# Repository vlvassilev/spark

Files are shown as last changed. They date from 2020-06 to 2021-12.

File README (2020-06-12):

Spark is a universal open hardware platform for networking
developed by Lightside Instruments AS.

The project includes schematic and PCB
design files for KiCAD and technical documentation for
production of a 19 inch rack mountable ESD Acrylic box.

The project is published by Lightside Instruments AS
under TAPR Open Hardware License. Read the LICENSE file
for details.

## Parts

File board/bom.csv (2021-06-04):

Reference | Quantity | Identifier | footprint | Value | Tolerance | Voltage | Current | Power | Mfr | Mfr Part # | Notes
P1 | 1 |  | 96boards:Pin_Header_SMD_2x20_Pitch2mm | CONN_02X20 |  |  |  |  | Molex | 87759-4051
P3 | 1 |  | 96boards:61083-063400LF | CONN_02X30 |  |  |  |  | Amphenol | 61083-064400LF
J11;J21;J31;J41;J51;J61 | 6 |  | spark:molex-sfp-plus-747540-101 | SFP+ |  |  |  |  |  | 74754-0101
J1;J2;J3;J4;J5;J6 | 6 |  | spark:molex-sfp-plus-747540-101 | SFP+ |  |  |  |  |  | 74441-0001
J12;J22;J32;J42;J52;J62 | 6 |  | spark:molex-sfp-plus-747540-101 | SFP+ |  |  |  |  |  | 74754-0011
J7 | 1 |  | spark:R-PDSS-B11 | PTH08T221W |  |  |  |  |  | PTH08T221WAZ
R102;R103;R105;R106;R107;R202;R203;R205;R206;R207;R302;R303;R305;R306;R307;R402;R403;R405;R406;R407;R502;R503;R505;R506;R507;R602;R603;R605;R606;R607 | 30 |  | Resistor_SMD:R_0402_1005Metric | 10K |  |  |  |  |  | CRCW040210K0FKEDC
C102;C104;C101;C103;C202;C204;C201;C203;C302;C304;C301;C303;C402;C404;C401;C403;C502;C504;C501;C503;C602;C604;C601;C603 | 24 |  | Capacitor_SMD:C_0402_1005Metric | 100nF |  |  |  |  |  | 885012205037
J10 | 1 |  | spark:PJ1-021-SMT-TR | Barrel_Jack |  |  |  |  |  | PJ1-021-SMT-TR
L102;L101;L202;L201;L302;L301;L402;L401;L502;L501;L602;L601 | 12 |  | Inductor_SMD:L_1210_3225Metric | 4.7uH |  |  |  |  |  | CM322522-4R7JL
C106;C105;C8;C206;C205;C306;C305;C406;C405;C506;C505;C606;C605 | 13 |  | Capacitor_SMD:C_1210_3225Metric | 22uF |  | >=16V |  |  |  | F931C226MBAAJ6 | TAJB226M016SNJ
D101;D201;D301;D401;D501;D601 | 6 |  | LED_SMD:LED_0402_1005Metric | ADM_LED |  |  |  |  |  | 150040VS73240
R101;R104;R201;R204;R301;R304;R401;R404;R501;R504;R601;R604 | 12 |  | Resistor_SMD:R_0402_1005Metric | 1K |  |  |  |  |  | RR0510P-102-D
D102;D202;D302;D402;D502;D602 | 6 |  | LED_SMD:LED_0402_1005Metric | ALARM_LED |  |  |  |  |  | 150040VS73240
R8 | 1 |  | Resistor_SMD:R_0402_1005Metric | 1K21 |  |  |  |  |  | ERJ-2RKF1211X
C7 | 1 |  | Capacitor_Tantalum_SMD:CP_EIA-7343-31_Kemet-D | 330uF |  |  |  |  |  | T491D227M016AT
C9 | 1 |  | Capacitor_Tantalum_SMD:CP_EIA-7343-31_Kemet-D | 220uF |  |  |  |  |  | T491D227M016AT
P2 | 1 |  | 96boards:Socket_Strip_SMD_2x20_Pitch2mm | Conn_02x20_Odd_Even |  |  |  |  | Amphenol | 55510-140LF
J8_1,J8_2 | 2 |  | Connector_PinHeader_2.00mm:PinHeader_2x30_P2.00mm_Vertical_SMD | Conn_02x30_Odd_Even |  |  |  |  | Samtec | TMM-115-01-L-D-SM | Or 1x TMM-130-01-L-D-SM
P5;P4 | 2 |  | Connector_PinHeader_2.54mm:PinHeader_2x20_P2.54mm_Vertical_SMD | Conn_02x20_Odd_Even |  |  |  |  | Harwin | M20-7812045 | Remove the mounting pegs with pleiers before placing the component
SW2 | 1 |  | Button_Switch_SMD:SW_DIP_SPSTx06_Slide_Omron_A6H-6101_W6.15mm_P1.27mm | SW_DIP_x06 |  |  |  |  |  | A6H-6101
P6 | 1 |  | spark:5177983-2 | CONN_02X30 |  |  |  |  | TE CONNECTIVITY | 1-5177983-2
SW1 | 1 |  | Button_Switch_THT:SW_Tactile_SPST_Angled_PTS645Vx83-2LFS | SW_Push |  |  |  |  |  | PTS645VK582LFS
R1 | 1 | * |  | 13.3K |  |  |  |  |  | ERA-2AEB1332X
U1 | 1 | * |  |  |  |  |  |  |  | LTM4624IY#PBF
U2 | 1 |  | Package_SO:SO-8_3.9x4.9mm_P1.27mm | PCA9306 |  |  |  |  |  | PCA9306D
R3,R4,R6,R7 | 4 |  | Resistor_SMD:R_0402_1005Metric | 4K7
R5 | 1 |  | Resistor_SMD:R_0402_1005Metric | 200K

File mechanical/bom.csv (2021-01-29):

Reference | Quantity | Mfr | Mfr Part # | Description
M1 | 4 | Wurth | 971080154 | Standoff 8mm_w_6mm_ext_thread
M2 | 22 | Wurth | 970060154 | Standoff Female-Female 6mm
M3 | 4 | Wurth | 971060154 | Standoff 6mm_w_6mm_ext_thread
M4 | 8 | Essentra | 302208059935 | Standoff Female-Female 8mm

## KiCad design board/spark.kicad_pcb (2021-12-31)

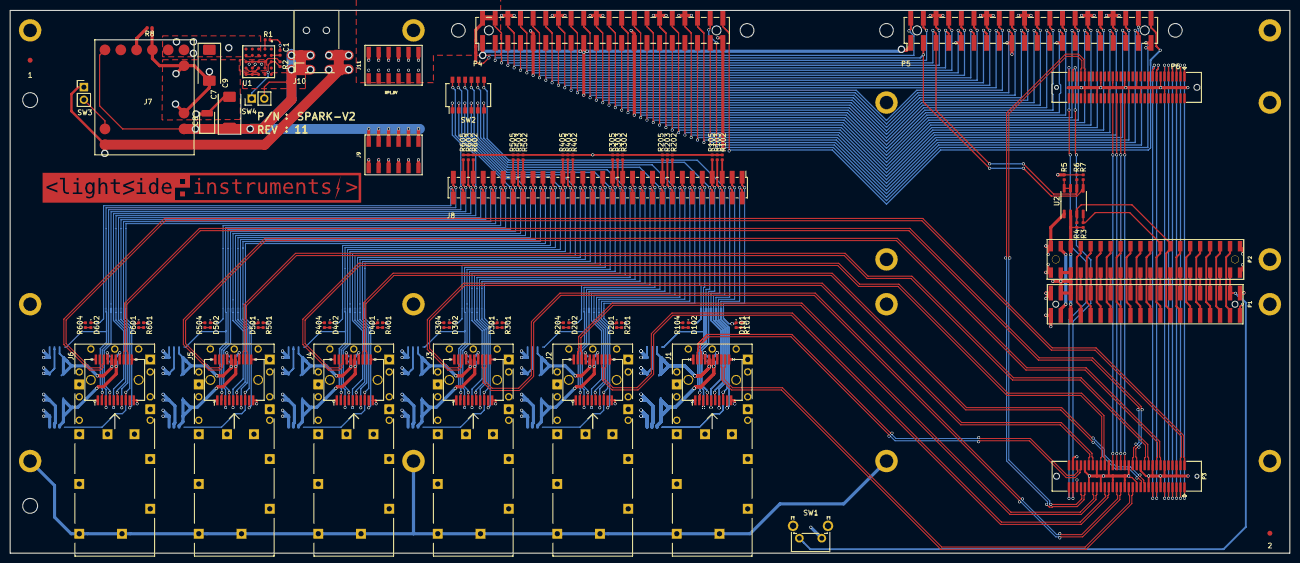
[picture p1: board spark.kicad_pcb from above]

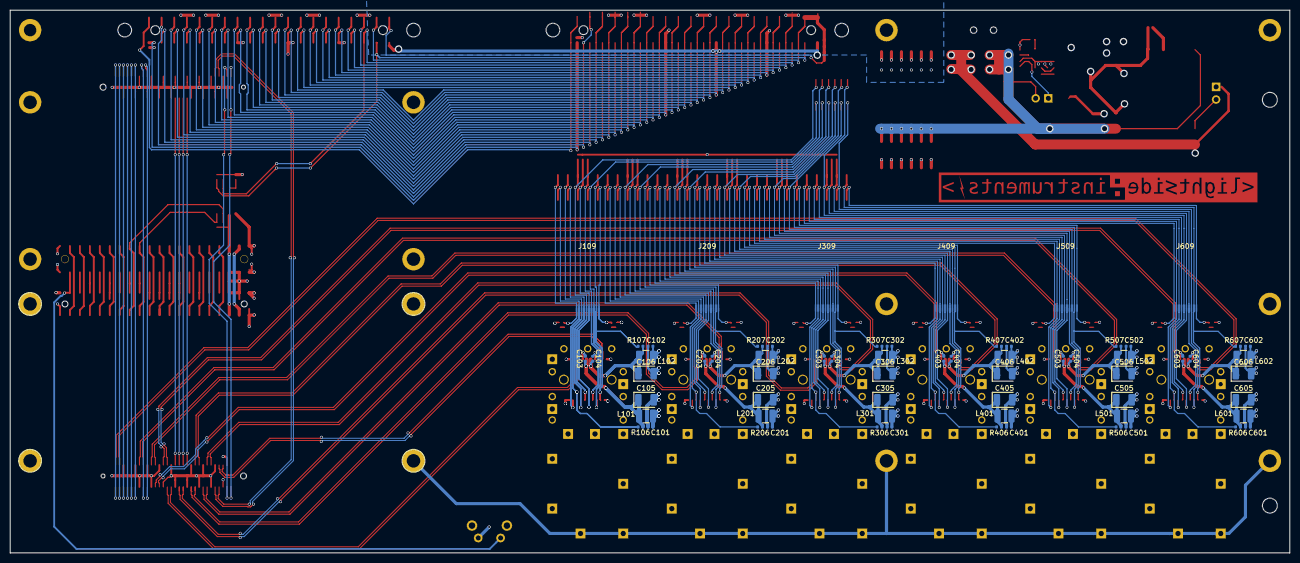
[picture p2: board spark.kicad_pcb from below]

Board: 4 copper layers, 257.0 x 109.0 mm, 145 parts (66 on the bottom side), 198 nets.

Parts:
1, 2: Fiducial_1mm_Mask3mm
C1: C; C_0402_1005Metric
C7: 330uF; CP_EIA-7343-31_Kemet-D
C8, C105, C106, C205, C206, C305, C306, C405, C406, C505, C506, C605, C606: 22uF; CP_EIA-3528-21_Kemet-B
C9: 220uF; CP_EIA-7343-31_Kemet-D
C101, C102, C103, C104, C201, C202, C203, C204, C301, C302, C303, C304, C401, C402, C403, C404, C501, C502, C503, C504, C601, C602, C603, C604: 100nF; C_0402_1005Metric
D101, D201, D301, D401, D501, D601: ADM_LED; LED_0402_1005Metric
D102, D202, D302, D402, D502, D602: ALARM_LED; LED_0402_1005Metric
J1, J2, J3, J4, J5, J6: SFP+; molex-sfp-plus-747540-101
J7: PTH08T221W; R-PDSS-B11
J8: Conn_02x30_Odd_Even; PinHeader_2x30_P2.00mm_Vertical_SMD
J9, J11: Conn_02x06_Odd_Even; Socket_Strip_SMD_2x6_Pitch2mm
J10: Barrel_Jack; PJ1-021-SMT-TR
J109, J209, J309, J409, J509, J609: Conn_01x10; sfp_header
L101, L102, L201, L202, L301, L302, L401, L402, L501, L502, L601, L602: 4.7uH; L_1210_3225Metric
P1: CONN_02X20; Pin_Header_SMD_2x20_Pitch2mm
P2: Conn_02x20_Odd_Even; Socket_Strip_SMD_2x20_Pitch2mm_Alignment_Pin
P3: CONN_02X30; 61083-063400LF
P4, P5: Conn_02x20_Odd_Even; PinSocket_2x20_P2.54mm_Vertical_Inverted_SMD_Alignment_Pin
P6: CONN_02X30; 5177983-2
R1: 13K3; C_0402_1005Metric
R2: 10K; C_0402_1005Metric
R3, R4, R6, R7: 4K7; R_0402_1005Metric
R5: 200K; R_0402_1005Metric
R8: 1K21; R_0402_1005Metric
R101, R104, R201, R204, R301, R304, R401, R404, R501, R504, R601, R604: 1K; R_0402_1005Metric
R102, R103, R105, R106, R107, R202, R203, R205, R206, R207, R302, R303, R305, R306, R307, R402, R403, R405, R406, R407, R502, R503, R505, R506, R507, R602, R603, R605, R606, R607: 10K; R_0402_1005Metric
SW1: SW_Push; SW_Tactile_SPST_Angled_PTS645Vx83-2LFS
SW2: SW_DIP_x06; SW_DIP_SPSTx06_Slide_Omron_A6H-6101_W6.15mm_P1.27mm
SW3, SW4: SW_DIP_x01; PinHeader_1x02_P2.54mm_Vertical
U1: LTM4624IYPBF; Analog_Devices_Inc-BGA-0-05-08-1905_Rev_C-0
U2: PCA9306; SO-8_3.9x4.9mm_P1.27mm

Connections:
+1V8: P1.35, P2.35, R3.1, R4.1, U2.2
+3V3: C9.1, C101.1, C102.1, C201.1, C202.1, C301.1, C302.1, C401.1, C402.1, C501.1, C502.1, C601.1, C602.1, J7.5, J7.6, L101.1, L102.1, L201.1, L202.1, L301.1, L302.1, L401.1, L402.1, L501.1, L502.1, L601.1, L602.1, P4.1, P4.17, P5.1, P5.17, R5.1, R6.1, R7.1, R101.1, R102.1, R103.1, R104.1, R105.1, R201.1, R202.1, R203.1, R204.1, R205.1, R301.1, R302.1, R303.1, R304.1, R305.1, R401.1, R402.1, R403.1, R404.1, R405.1, R501.1, R502.1, R503.1, R504.1, R505.1, R601.1, R602.1, R603.1, R604.1, R605.1, U1.C1, U1.D1, U1.D2, U1.E1, U1.E2
+5V: P1.37, P2.37
CHASSIS: J1.CAGE, J2.CAGE, J3.CAGE, J4.CAGE, J5.CAGE, J6.CAGE
CLK0/CSI0_MCLK: P3.15, P6.15
CLK1/CSI1_MCLK: P3.17, P6.17
CSI0_C+: J6.18, P3.2
CSI0_C-: J6.19, P3.4
CSI0_D1+: J5.18, P3.14
CSI0_D1-: J5.19, P3.16
CSI0_D2+: J5.13, P3.20
CSI0_D2-: J5.12, P3.22
CSI0_D3+: J6.13, P3.26
CSI0_D3-: J6.12, P3.28
CSI1_C+: J1.18, P3.54
CSI1_C-: J1.19, P3.56
CSI1_D0+: J4.18, P3.42
CSI1_D0-: J4.19, P3.44
CSI1_D1+: J3.18, P3.48
CSI1_D1-: J3.19, P3.50
DSI_CLK+: J4.13, P3.21
DSI_CLK-: J4.12, P3.23
DSI_D0+: J1.13, P3.27
DSI_D0-: J1.12, P3.29
DSI_D1+: J3.13, P3.33
DSI_D1-: J3.12, P3.35
DSI_D2+: J2.13, P3.39
DSI_D2-: J2.12, P3.41
DSI_D3+: J2.18, P3.45
DSI_D3-: J2.19, P3.47
GND: C1.2, C7.2, C8.2, C9.2, C101.2, C102.2, C103.2, C104.2, C105.2, C106.2, C201.2, C202.2, C203.2, C204.2, C205.2, C206.2, C301.2, C302.2, C303.2, C304.2, C305.2, C306.2, C401.2, C402.2, C403.2, C404.2, C405.2, C406.2, C501.2, C502.2, C503.2, C504.2, C505.2, C506.2, C601.2, C602.2, C603.2, C604.2, C605.2, C606.2, J1.1, J1.10, J1.11, J1.14, J1.17, J1.20, J2.1, J2.10, J2.11, J2.14, J2.17, J2.20, J3.1, J3.10, J3.11, J3.14, J3.17, J3.20, J4.1, J4.10, J4.11, J4.14, J4.17, J4.20, J5.1, J5.10, J5.11, J5.14, J5.17, J5.20, J6.1, J6.10, J6.11, J6.14, J6.17, J6.20, J7.1, J7.3, J7.4, J7.7, J9.1, J9.3, J9.5, J9.7, J9.9, J9.11, J10.2, J10.3, J11.2, J11.4, J11.6, J11.8, J11.10, J11.12, P1.1, P1.2, P1.39, P1.40, P2.1, P2.2, P2.39, P2.40, P3.6, P3.12, P3.13, P3.18, P3.19, P3.24, P3.25, P3.30, P3.31, P3.37, P3.40, P3.43, P3.46, P3.49, P3.52, P3.55, P3.58, P4.6, P4.9, P4.14, P4.20, P4.25, P4.30, P4.34, P4.39, P5.6, P5.9, P5.14, P5.20, P5.25, P5.30, P5.34, P5.39, P6.6, P6.12, P6.13, P6.18, P6.19, P6.24, P6.25, P6.30, P6.31, P6.37, P6.40, P6.43, P6.46, P6.49, P6.52, P6.55, P6.58, R1.2, R2.2, R8.1, SW1.1, SW3.1, U1.B3, U1.B4, U1.C3, U1.D3, U1.D4, U1.E3, U2.1
GPIO_A: P1.23, P2.23
GPIO_B: P1.24, P2.24
GPIO_C: P1.25, P2.25
GPIO_D: P1.26, P2.26
GPIO_E: P1.27, P2.27
GPIO_F: P1.28, P2.28
GPIO_G: P1.29, P2.29
GPIO_H: P1.30, P2.30
GPIO_I: P1.31, P2.31
GPIO_J: P1.32, P2.32
GPIO_K: P1.33, P2.33
GPIO_L: P1.34, P2.34
HSIC_DATA: P3.59, P6.59
HSIC_STR: P3.57, P6.57
I2C0_SCL: P1.15, P2.15, R4.2, U2.3
I2C0_SDA: P1.17, P2.17, R3.2, U2.4
I2C1_SCL: P1.19, P2.19
I2C1_SDA: P1.21, P2.21
I2C2_SCL: P3.32, P6.32
I2C2_SDA: P3.34, P6.34
I2C3_SCL: P3.36, P6.36
I2C3_SDA: P3.38, P6.38
unnamed: C1.1, U1.A2
unnamed: D101.2, R101.2
unnamed: D102.2, R104.2
unnamed: D201.2, R201.2
unnamed: D202.2, R204.2
unnamed: D301.2, R301.2
unnamed: D302.2, R304.2
unnamed: D401.2, R401.2
unnamed: D402.2, R404.2
unnamed: D501.2, R501.2
unnamed: D502.2, R504.2
unnamed: D601.2, R601.2
unnamed: D602.2, R604.2
unnamed: J7.8, R8.2
unnamed: J7.11, SW3.2
unnamed: P4.7, P5.7
unnamed: P4.8, P5.8
unnamed: P4.10, P5.10
unnamed: P4.11, P5.11
unnamed: P4.12, P5.12
unnamed: P4.13, P5.13
unnamed: P4.15, P5.15
unnamed: P4.16, P5.16
unnamed: P4.18, P5.18
unnamed: P4.19, P5.19
unnamed: P4.21, P5.21
unnamed: P4.22, P5.22
unnamed: P4.23, P5.23
unnamed: P4.24, P5.24
unnamed: P4.26, P5.26
unnamed: P4.27, P5.27
unnamed: P4.28, P5.28
unnamed: P4.29, P5.29
unnamed: P4.31, P5.31
unnamed: P4.32, P5.32
unnamed: P4.33, P5.33
unnamed: P4.35, P5.35
unnamed: P4.36, P5.36
unnamed: P4.37, P5.37
unnamed: P4.38, P5.38
unnamed: P4.40, P5.40
unnamed: R1.1, U1.B1
unnamed: R2.1, SW4.1, U1.A3
unnamed: R5.2, U2.7, U2.8
unnamed: U1.C4, U1.E4
PCM_CLK: P1.18, P2.18
PCM_DI: P1.22, P2.22
PCM_DO: P1.20, P2.20
PCM_FS: P1.16, P2.16
PWR_BTN_N: P1.4, P2.4, SW1.2
RPI_5V: J11.1, J11.3, J11.5, J11.7, J11.9, J11.11, P4.2, P4.4, P5.2, P5.4
RPI_I2C_SCL: P4.5, P5.5, R6.2, U2.6
RPI_I2C_SDA: P4.3, P5.3, R7.2, U2.5
RST_BTN_N: P1.6, P2.6
SD_CMD/SPI1_DIN: P3.11, P6.11
SD_DAT0/SPI1_DOUT: P3.1, P6.1
SD_DAT1: P3.3, P6.3
SD_DAT2: P3.5, P6.5
SD_DAT3/SPI1_CS: P3.7, P6.7
SD_SCLK/SPI1_SCLK: P3.9, P6.9
SFP0_ADM_LED: D101.1, J8.1, J109.1
SFP0_ALARM_LED: D102.1, J8.10, J109.10
SFP0_MOD_ABS: J1.6, J8.5, J109.5, R102.2, SW2.7
SFP0_RS0: J1.7, J8.4, J109.4
SFP0_RS1: J1.9, J8.2, J109.2
SFP0_RX_LOS: J1.8, J8.3, J109.3, R106.2
SFP0_SCL: J1.5, J8.6, J109.6, R103.2
SFP0_SDA: J1.4, J8.7, J109.7, R105.2
SFP0_TX_DISABLE: J1.3, J8.8, J109.8, SW2.6
SFP0_TX_FAULT: J1.2, J8.9, J109.9, R107.2
SFP0_VCC_R: C104.1, C106.1, J1.16, L102.2, R107.1
SFP0_VCC_T: C103.1, C105.1, J1.15, L101.2, R106.1
SFP1_ADM_LED: D201.1, J8.11, J209.1
SFP1_ALARM_LED: D202.1, J8.20, J209.10
SFP1_MOD_ABS: J2.6, J8.15, J209.5, R202.2, SW2.8
SFP1_RS0: J2.7, J8.14, J209.4
SFP1_RS1: J2.9, J8.12, J209.2
SFP1_RX_LOS: J2.8, J8.13, J209.3, R206.2
SFP1_SCL: J2.5, J8.16, J209.6, R203.2
SFP1_SDA: J2.4, J8.17, J209.7, R205.2
SFP1_TX_DISABLE: J2.3, J8.18, J209.8, SW2.5
SFP1_TX_FAULT: J2.2, J8.19, J209.9, R207.2
SFP1_VCC_R: C204.1, C206.1, J2.16, L202.2, R207.1
SFP1_VCC_T: C203.1, C205.1, J2.15, L201.2, R206.1
SFP2_ADM_LED: D301.1, J8.21, J309.1
SFP2_ALARM_LED: D302.1, J8.30, J309.10
SFP2_MOD_ABS: J3.6, J8.25, J309.5, R302.2, SW2.9
SFP2_RS0: J3.7, J8.24, J309.4
SFP2_RS1: J3.9, J8.22, J309.2
SFP2_RX_LOS: J3.8, J8.23, J309.3, R306.2
SFP2_SCL: J3.5, J8.26, J309.6, R303.2
SFP2_SDA: J3.4, J8.27, J309.7, R305.2
SFP2_TX_DISABLE: J3.3, J8.28, J309.8, SW2.4
SFP2_TX_FAULT: J3.2, J8.29, J309.9, R307.2
SFP2_VCC_R: C304.1, C306.1, J3.16, L302.2, R307.1
SFP2_VCC_T: C303.1, C305.1, J3.15, L301.2, R306.1
SFP3_ADM_LED: D401.1, J8.31, J409.1
SFP3_ALARM_LED: D402.1, J8.40, J409.10
SFP3_MOD_ABS: J4.6, J8.35, J409.5, R402.2, SW2.10
SFP3_RS0: J4.7, J8.34, J409.4
SFP3_RS1: J4.9, J8.32, J409.2
SFP3_RX_LOS: J4.8, J8.33, J409.3, R406.2
SFP3_SCL: J4.5, J8.36, J409.6, R403.2
SFP3_SDA: J4.4, J8.37, J409.7, R405.2
SFP3_TX_DISABLE: J4.3, J8.38, J409.8, SW2.3
SFP3_TX_FAULT: J4.2, J8.39, J409.9, R407.2
SFP3_VCC_R: C404.1, C406.1, J4.16, L402.2, R407.1
SFP3_VCC_T: C403.1, C405.1, J4.15, L401.2, R406.1
SFP4_ADM_LED: D501.1, J8.41, J509.1
SFP4_ALARM_LED: D502.1, J8.50, J509.10
SFP4_MOD_ABS: J5.6, J8.45, J509.5, R502.2, SW2.11
SFP4_RS0: J5.7, J8.44, J509.4
SFP4_RS1: J5.9, J8.42, J509.2
SFP4_RX_LOS: J5.8, J8.43, J509.3, R506.2
SFP4_SCL: J5.5, J8.46, J509.6, R503.2
SFP4_SDA: J5.4, J8.47, J509.7, R505.2
SFP4_TX_DISABLE: J5.3, J8.48, J509.8, SW2.2
SFP4_TX_FAULT: J5.2, J8.49, J509.9, R507.2
SFP4_VCC_R: C504.1, C506.1, J5.16, L502.2, R507.1
SFP4_VCC_T: C503.1, C505.1, J5.15, L501.2, R506.1
SFP5_ADM_LED: D601.1, J8.51, J609.1
SFP5_ALARM_LED: D602.1, J8.60, J609.10
SFP5_MOD_ABS: J6.6, J8.55, J609.5, R602.2, SW2.12
SFP5_RS0: J6.7, J8.54, J609.4
SFP5_RS1: J6.9, J8.52, J609.2
SFP5_RX_LOS: J6.8, J8.53, J609.3, R606.2
SFP5_SCL: J6.5, J8.56, J609.6, R603.2
SFP5_SDA: J6.4, J8.57, J609.7, R605.2
SFP5_TX_DISABLE: J6.3, J8.58, J609.8, SW2.1
SFP5_TX_FAULT: J6.2, J8.59, J609.9, R607.2
SFP5_VCC_R: C604.1, C606.1, J6.16, L602.2, R607.1
SFP5_VCC_T: C603.1, C605.1, J6.15, L601.2, R606.1
SPIO_CS: P1.12, P2.12
SPIO_DIN: P1.10, P2.10
SPIO_DOUT: P1.14, P2.14
SPIO_SCL: P1.8, P2.8
SYS_DCIN: C7.1, C8.1, J7.2, J7.10, J9.2, J9.4, J9.6, J9.8, J9.10, J9.12, J10.1, P1.36, P1.38, P2.36, P2.38, SW4.2, U1.C5, U1.D5, U1.E5
UART0_CTS: P1.3, P2.3
UART0_RTS: P1.9, P2.9
UART0_RX: P1.7, P2.7
UART0_TX: P1.5, P2.5
UART1_RX: P1.13, P2.13
UART1_TX: P1.11, P2.11
USB_D+: P3.51, P6.51
USB_D-: P3.53, P6.53

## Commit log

2019-11-02 Initial release
    [spark.kicad_pcb, spark.sch]
2020-06-12 Release 1.0
    [bom.csv, spark.kicad_pcb, spark.sch]
2020-07-16 Release 2.0
    [bom.csv, spark.kicad_pcb, spark.sch]
2020-08-18 Release 2.0-2
    [spark.kicad_pcb, spark.sch]
2020-10-28 Release 2.0-3
    [spark.kicad_pcb, spark.sch]
2021-01-29 Release 2.0-4
    [bom.csv, spark.kicad_pcb, spark.sch]
2021-02-07 Release 2.0-5
    [spark.kicad_pcb, spark.sch]
2021-02-19 Release 2.0-6
    [spark.kicad_pcb, spark.sch]
2021-02-20 Release 2.0-7
    [spark.kicad_pcb, spark.sch]
2021-06-04 Release 2.0-8
    [bom.csv, spark.kicad_pcb, spark.sch]
2021-06-04 Release 2.0-9
    [bom.csv, spark.kicad_pcb, spark.sch]
2021-12-05 Release 2.0-10
    [spark.kicad_pcb, spark.sch]
2021-12-31 Release 2.0-11
    [spark.kicad_pcb, spark.sch]
